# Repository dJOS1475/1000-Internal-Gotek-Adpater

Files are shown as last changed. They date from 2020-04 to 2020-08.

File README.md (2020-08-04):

# 1000-Internal-Gotek-Adpater
Tandy 1000 Internal Gotek Adpater

This Tandy 1000 Internal Gotek Adapter allows you to use Gotek Virtual Floppy Drives with Tandy 1000's that send power over the Floppy cable.

Tandy 1000's that have power supplied via the Floppy Cable include the SL/2, TX, TL, TL/2, TL/3.

I made these because many folks wanted to use Gotek Virtual Floppy Drives with their Tandy's but due to the non-standard power-over-cable-design were unable to.

I highly recommend using the free FlashFloppy Firmware on Gotek Drives as the stock FW is quite poor. On my TL/2, I found that the FlashFloppy FF.CFG file needs the "pin34" option set to "chg" to enable Disk Change detection.

My Store can be found here: https://www.tindie.com/stores/CyberneticSys/

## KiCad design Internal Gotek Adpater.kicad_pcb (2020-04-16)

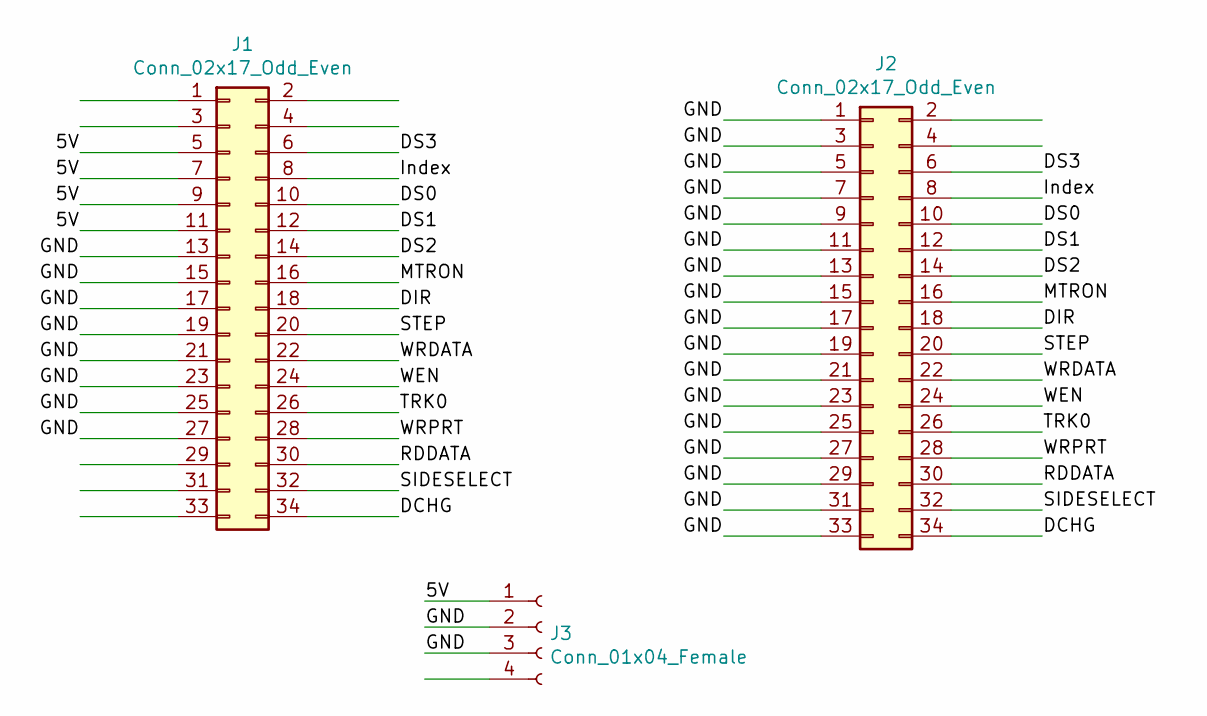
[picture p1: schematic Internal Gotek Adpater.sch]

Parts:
J1: Conn_02x17_Odd_Even; IDC34M
J2: Conn_02x17_Odd_Even; IDC34F
J3: Conn_01x04_Female; PinSocket_1x04_P2.54mm_Vertical

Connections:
/5V: J1.5, J1.7, J1.9, J1.11, J3.1
/DCHG: J1.34, J2.34
/DIR: J1.18, J2.18
/DS0: J1.10, J2.10
/DS1: J1.12, J2.12
/DS2: J1.14, J2.14
/DS3: J1.6, J2.6
/GND: J1.13, J1.15, J1.17, J1.19, J1.21, J1.23, J1.25, J1.27, J2.1, J2.3, J2.5, J2.7, J2.9, J2.11, J2.13, J2.15, J2.17, J2.19, J2.21, J2.23, J2.25, J2.27, J2.29, J2.31, J2.33, J3.2, J3.3
/Index: J1.8, J2.8
/MTRON: J1.16, J2.16
/RDDATA: J1.30, J2.30
/SIDESELECT: J1.32, J2.32
/STEP: J1.20, J2.20
/TRK0: J1.26, J2.26
/WEN: J1.24, J2.24
/WRDATA: J1.22, J2.22
/WRPRT: J1.28, J2.28

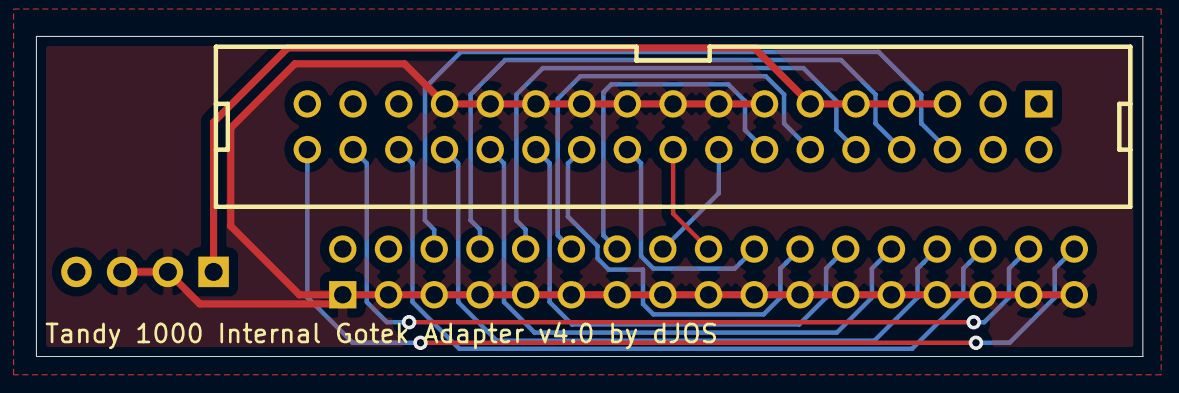
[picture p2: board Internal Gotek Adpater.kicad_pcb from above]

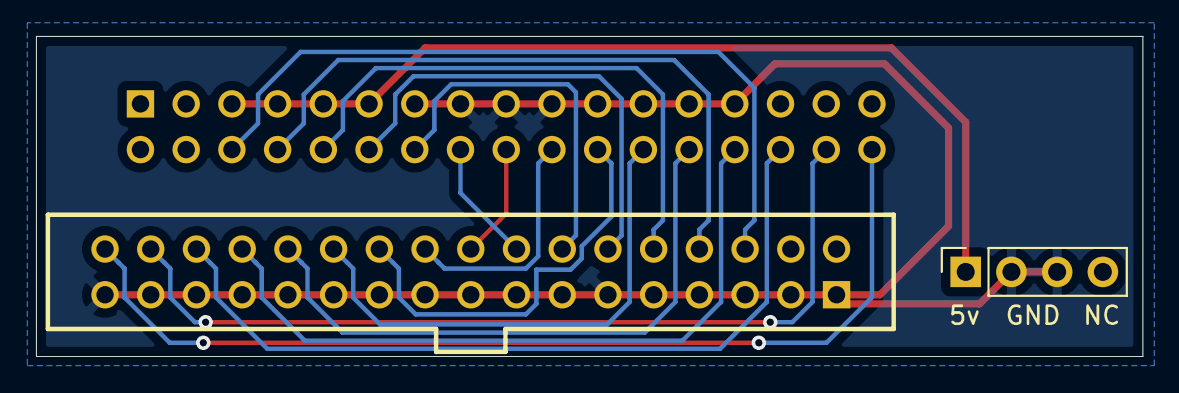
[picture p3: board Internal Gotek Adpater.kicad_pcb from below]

Board: 2 copper layers, 61.5 x 17.8 mm, 3 parts (2 on the bottom side), 17 nets.
